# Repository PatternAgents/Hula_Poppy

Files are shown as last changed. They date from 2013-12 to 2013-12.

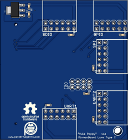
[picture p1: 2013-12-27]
Hula_Poppy/images/Hula_Poppy_thumb.png

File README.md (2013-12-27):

Hula Poppy
=============

PatternAgents Hula Poppy - Pmod Lure for Intel MinnowBoard

[PatternAgents Hula Poppy  
*PatternAgents Hula Poppy*](http://www.patternagents.com/projects/Hula_Poppy.html)

PatternAgents Hula Poppy - Pmod Lure for Intel MinnowBoard is a small adaptor board that allows
the Intel MinnowBoard to support Pmod Modules.

This work is licensed under a Creative Commons Attribution-ShareAlike 4.0 International License
[  
*Licensing CC BY-SA 4.0*](http://creativecommons.org/licenses/by-sa/4.0/)

It may be used for Educational, Personal, or Commercial Use, provided you keep these notices,
attribution, and share-alike. When you apply these licenses to material you create, 
it meets the Freedom Defined definition of a "Free Cultural Work". 
Free cultural works are the ones that can be most readily used, shared, 
and remixed by others, and go furthest toward creating a commons of freely reusable materials.

-------------------------------------------------------------------------------------------

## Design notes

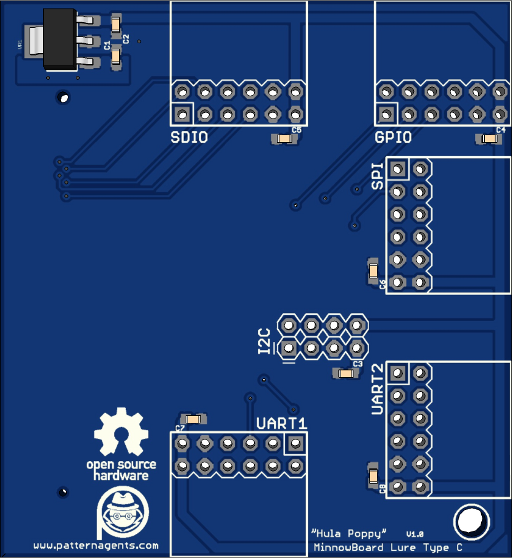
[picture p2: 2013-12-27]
Hula_Poppy/images/Hula_Poppy_top.png

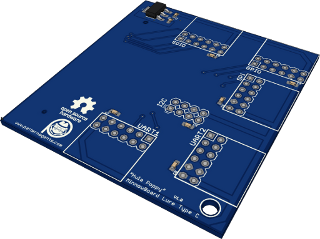
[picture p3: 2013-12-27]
Hula_Poppy/images/Hula_Poppy_model.png

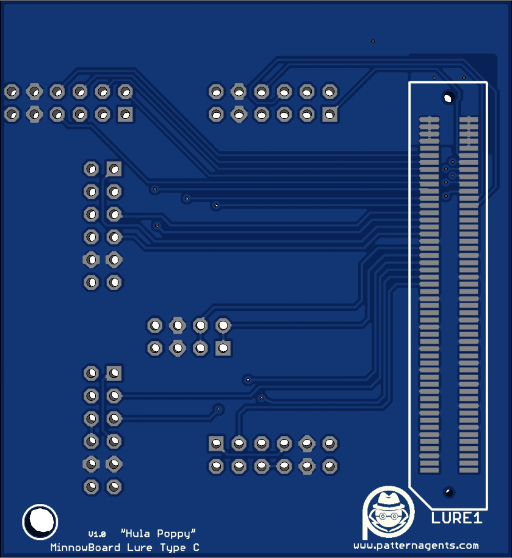
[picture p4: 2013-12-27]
Hula_Poppy/images/Hula_Poppy_bot.png

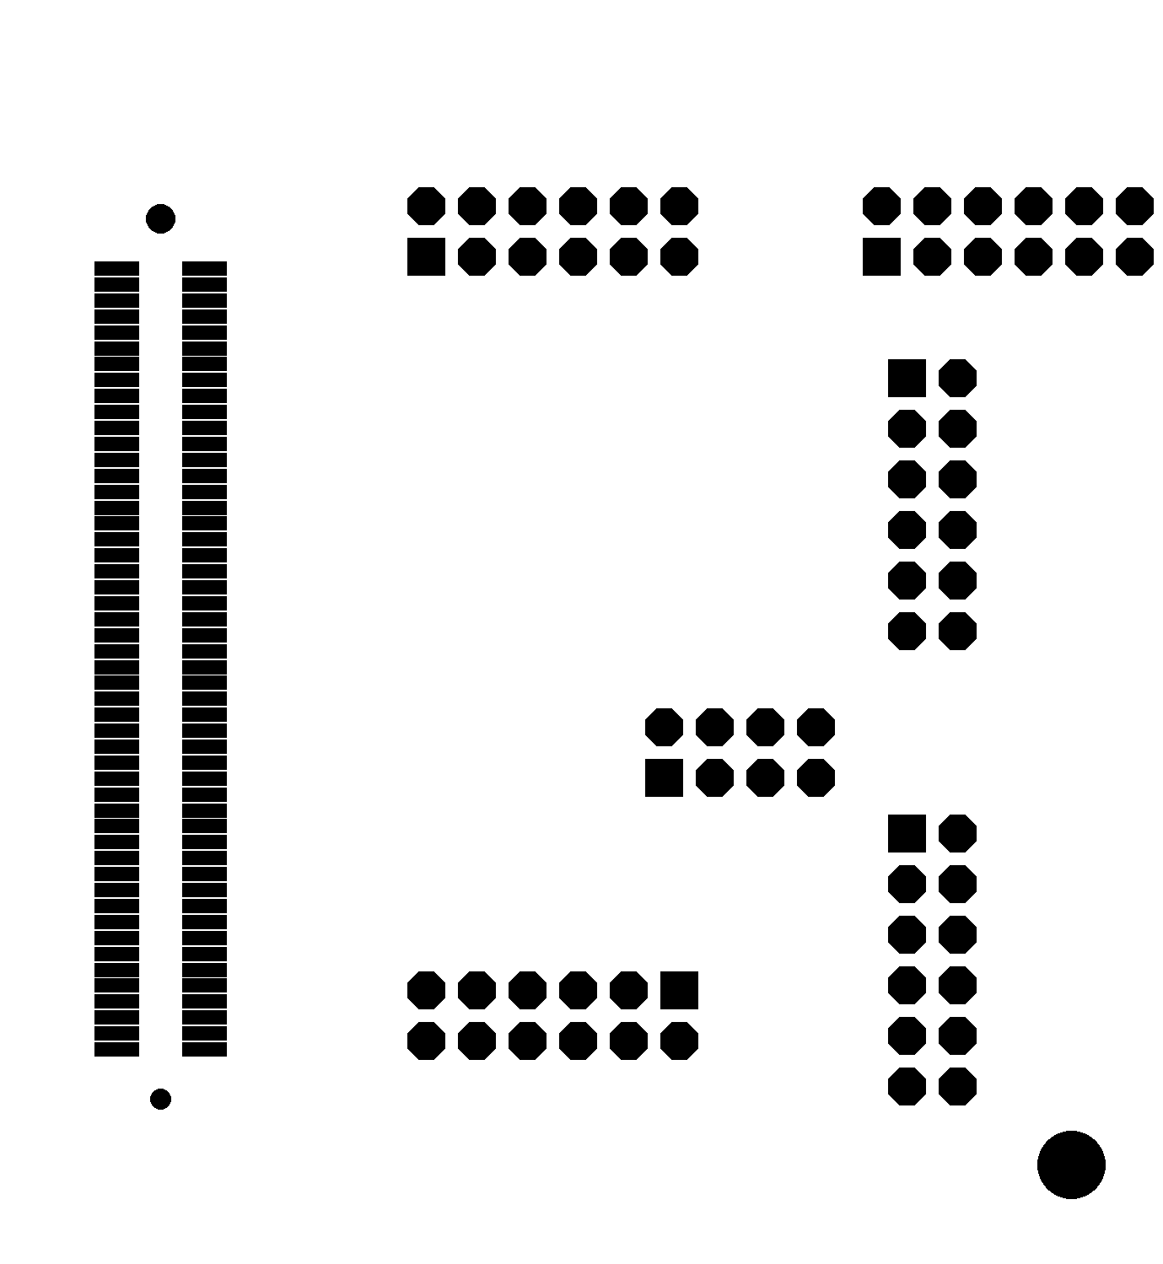
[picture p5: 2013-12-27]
Hula_Poppy/eagleUp/eagleUp_hula_poppy_bottom_mask.png

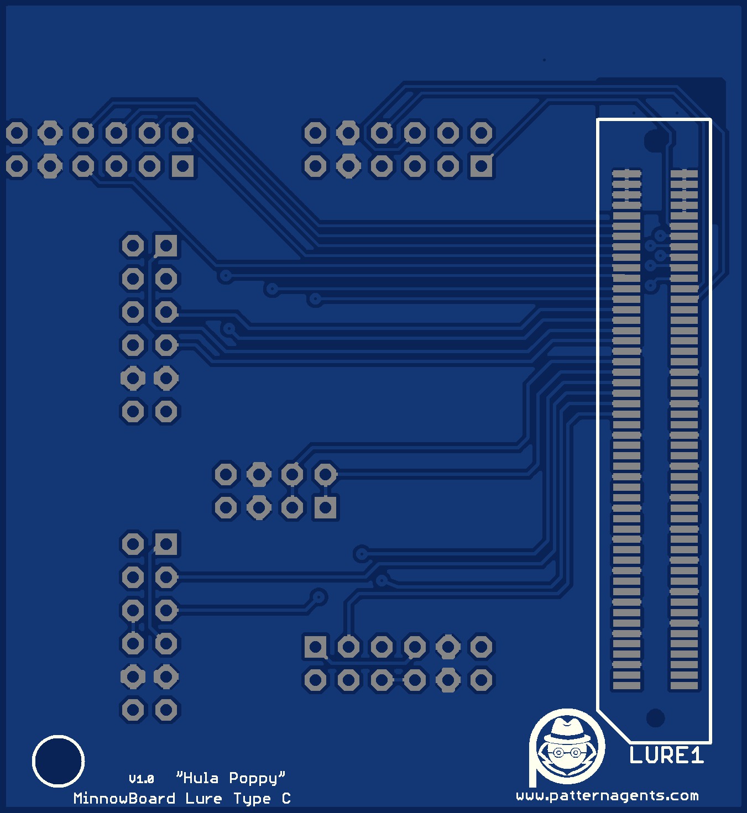
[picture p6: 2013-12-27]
Hula_Poppy/eagleUp/eagleUp_hula_poppy_board_bottom.jpg

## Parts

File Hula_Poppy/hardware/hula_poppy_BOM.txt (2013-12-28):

Partlist exported from hula_poppy.sch at 12/26/2013 7:46:43 PM

Part  Value                     Device                    Package               Description                                                                    
C1    10uF/6.3V                 CAP0603-CAP               0603-CAP              Capacitor                                                                      
C2    10uF/6.3V                 CAP0603-CAP               0603-CAP              Capacitor                                                                      
C3    0.1uF/6.3V                CAP0603-CAP               0603-CAP              Capacitor                                                                      
C4    0.1uF/6.3V                CAP0603-CAP               0603-CAP              Capacitor                                                                      
C5    0.1uF/6.3V                CAP0603-CAP               0603-CAP              Capacitor                                                                      
C6    0.1uF/6.3V                CAP0603-CAP               0603-CAP              Capacitor                                                                      
C7    0.1uF/6.3V                CAP0603-CAP               0603-CAP              Capacitor                                                                      
C8    0.1uF/6.3V                CAP0603-CAP               0603-CAP              Capacitor                                                                      
GPIO  PA_PMOD_GPIO_DIL_HOST     PA_PMOD_GPIO_DIL_HOST     PA_PMOD_DIL_FEMALE    PatternAgents Peripheral Module GPIO (Type 1A) Pattern                         
I2C   PA_PMOD_I2C_DIL_CABLE     PA_PMOD_I2C_DIL_CABLE     PA_PMOD_I2C_CABLE     PatternAgents Peripheral Module I2C (Standard) Pattern                         
LURE1 PA_MINNOW_LURE_BRD_TYPE_C PA_MINNOW_LURE_BRD_TYPE_C PA_LURE_TYPE_C        PatternAgents Minnow Lure Pattern                                              
SDIO  PA_PMOD_SDIO_DIL_HOST     PA_PMOD_SDIO_DIL_HOST     PA_PMOD_DIL_FEMALE    PatternAgents Peripheral Module SDIO (Type 2B) Pattern                         
SPI   PA_PMOD_SPI_DIL_HOST      PA_PMOD_SPI_DIL_HOST      PA_PMOD_DIL_FEMALE    PatternAgents Peripheral Module SPI (Type 2A) Pattern                          
U$6   PA_LOGO_SYMMED            PA_LOGO_SYMMED            PA_LOGO_AGENT_MED_SYM PatternAgents Logo Symbol                                                      
U$8   OSHW_LOGO_SYMWTXT         OSHW_LOGO_SYMWTXT         OSHW_LOGO_TEXT_SYM    OSHW_LOGO_SYM                                                                  
U$10  PA_LOGO_SYMMED            PA_LOGO_SYMMED            PA_LOGO_AGENT_MED_SYM PatternAgents Logo Symbol                                                      
UART1 PA_PMOD_UART_DIL_HOST     PA_PMOD_UART_DIL_HOST     PA_PMOD_DIL_FEMALE    PatternAgents Peripheral Module UART (Type 4A) Pattern                         
UART2 PA_PMOD_UART_DIL_HOST     PA_PMOD_UART_DIL_HOST     PA_PMOD_DIL_FEMALE    PatternAgents Peripheral Module UART (Type 4A) Pattern                         
VR1   V_REG_MIC2920             V_REG_MIC2920             SOT223                MIC2920A (http://www.micrel.com/_PDF/mic2920.pdf) - 400mA output LDO Regulator

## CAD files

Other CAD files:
Hula_Poppy/eagleUp/hula_poppy.skp

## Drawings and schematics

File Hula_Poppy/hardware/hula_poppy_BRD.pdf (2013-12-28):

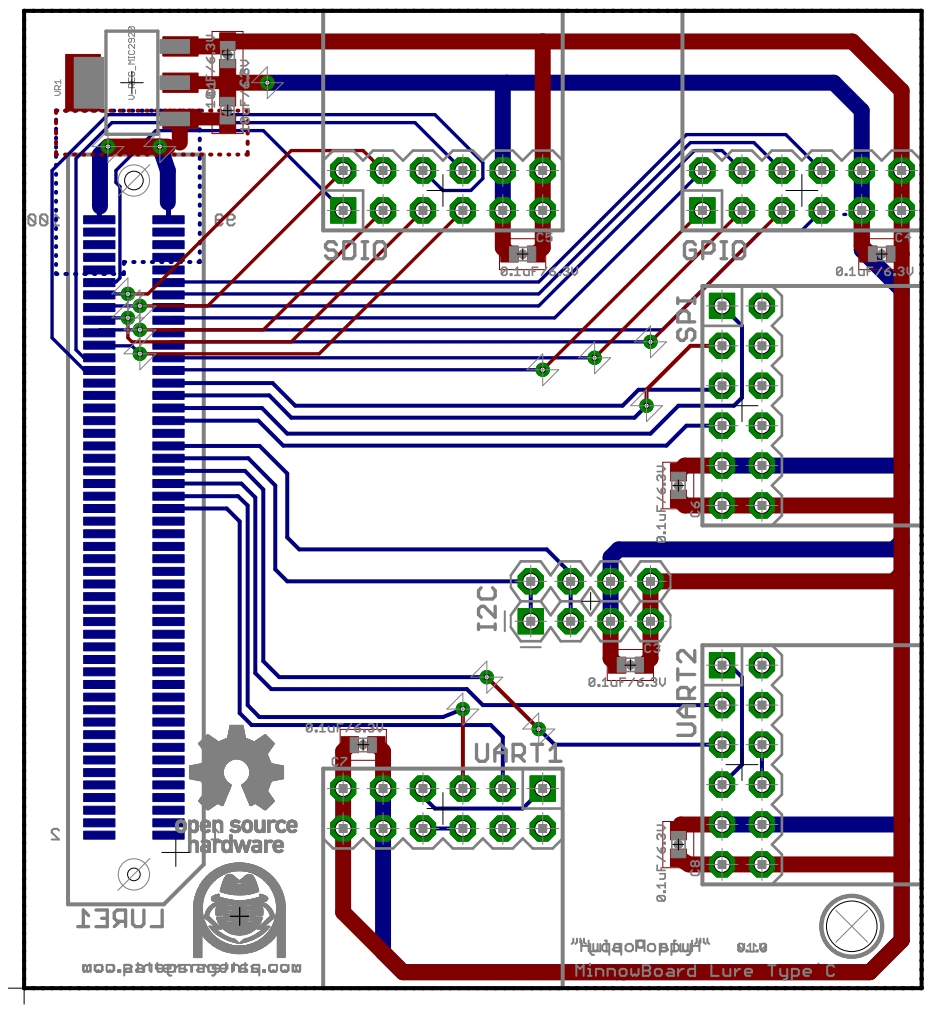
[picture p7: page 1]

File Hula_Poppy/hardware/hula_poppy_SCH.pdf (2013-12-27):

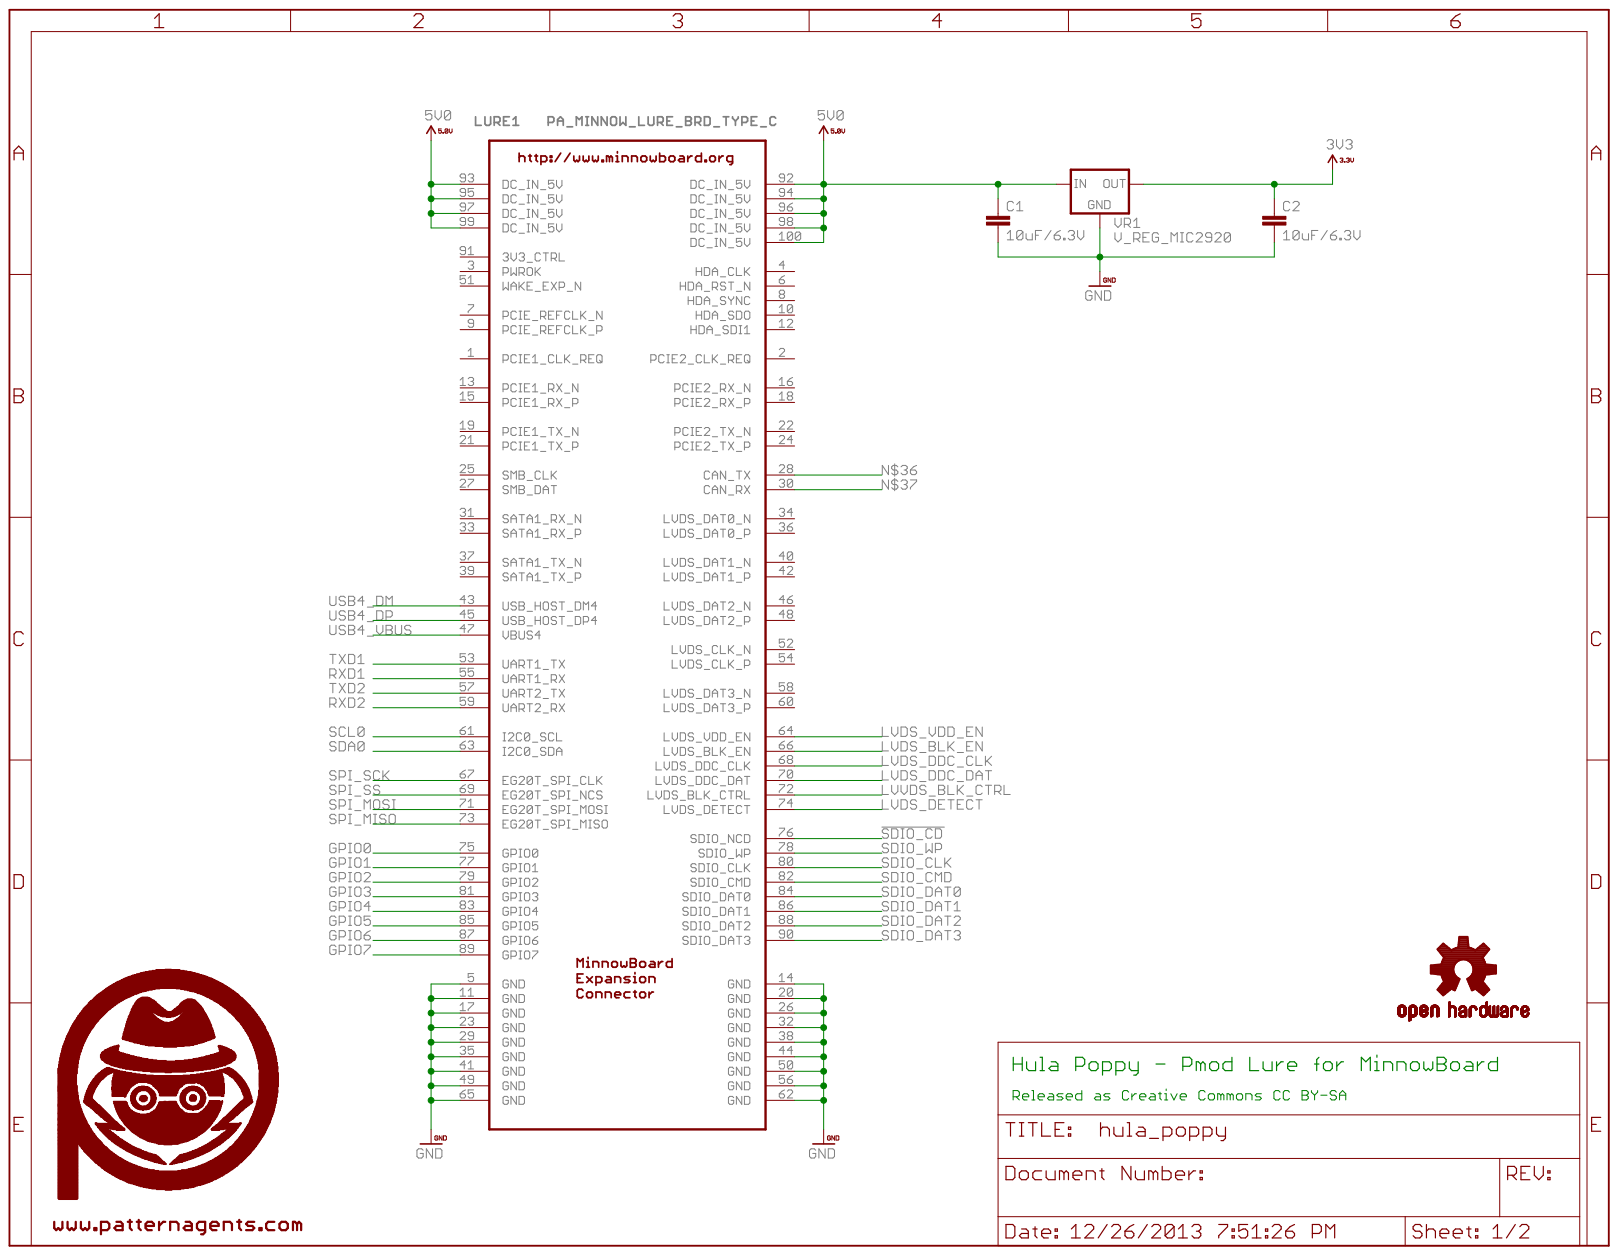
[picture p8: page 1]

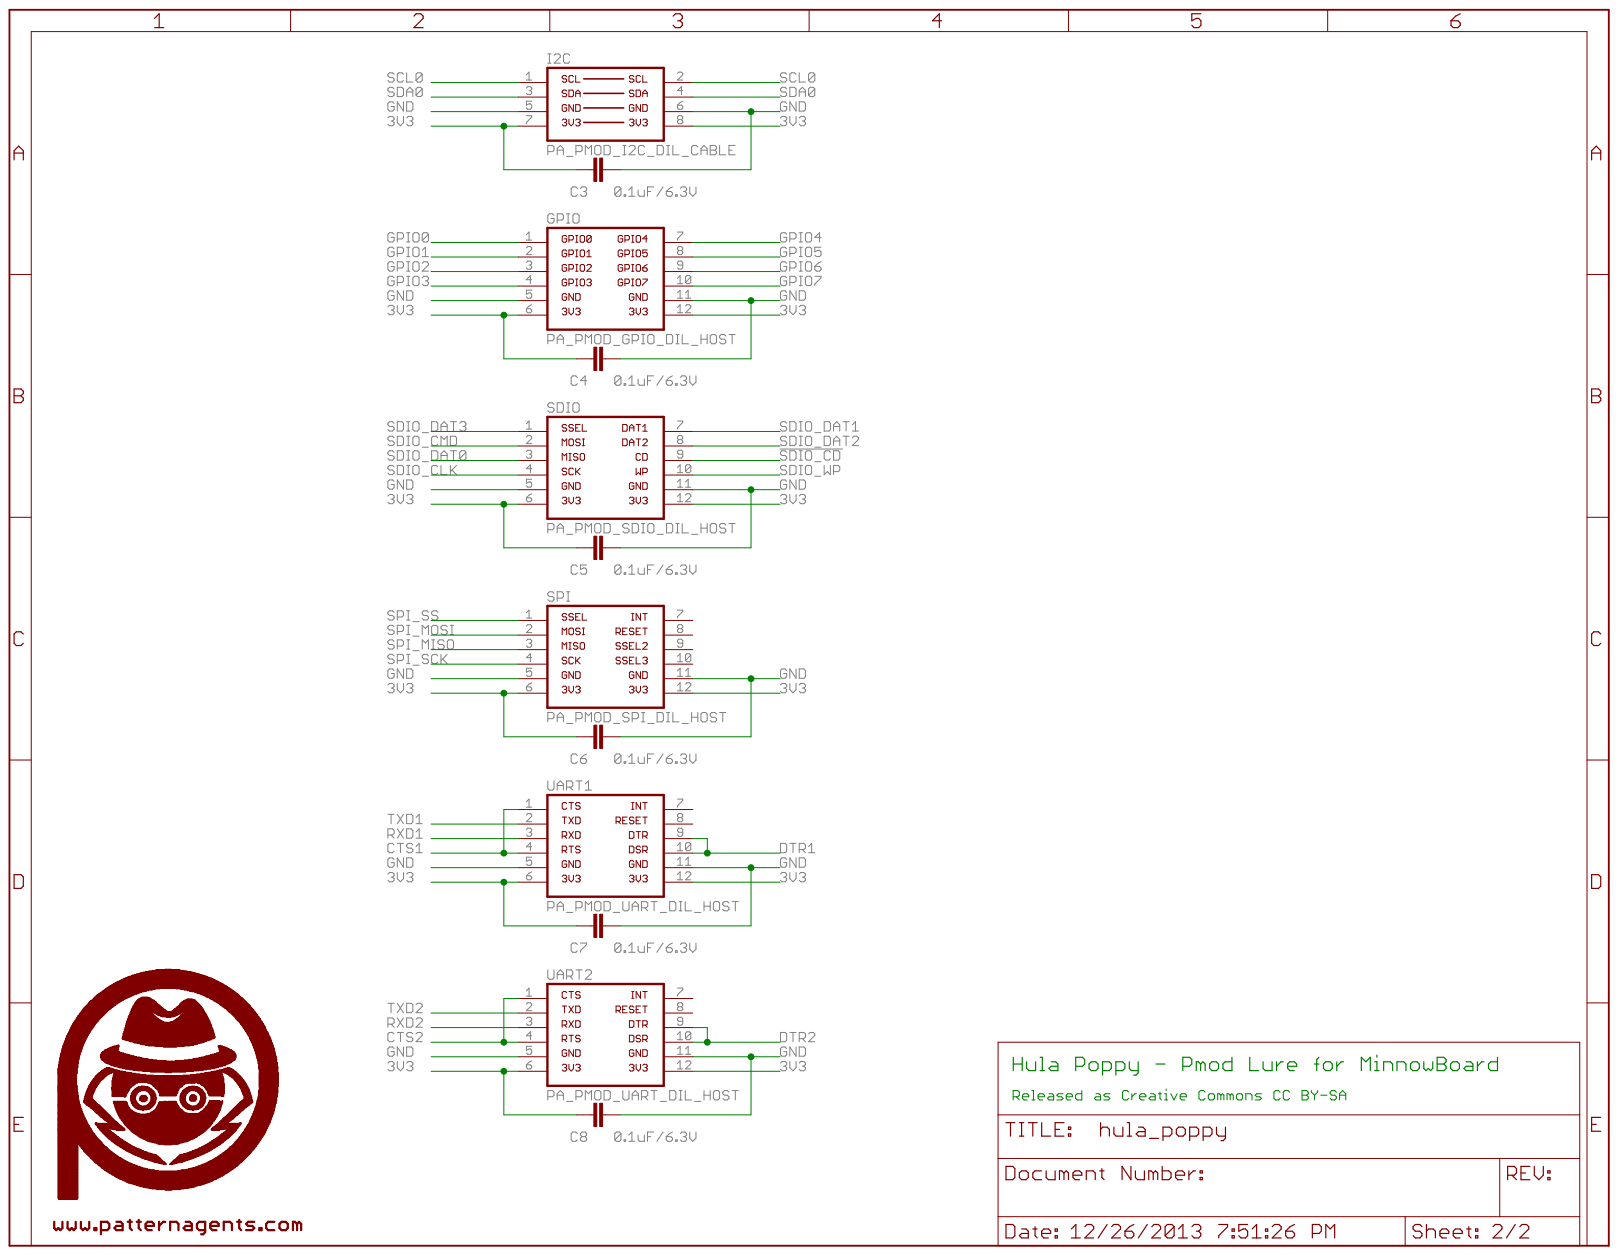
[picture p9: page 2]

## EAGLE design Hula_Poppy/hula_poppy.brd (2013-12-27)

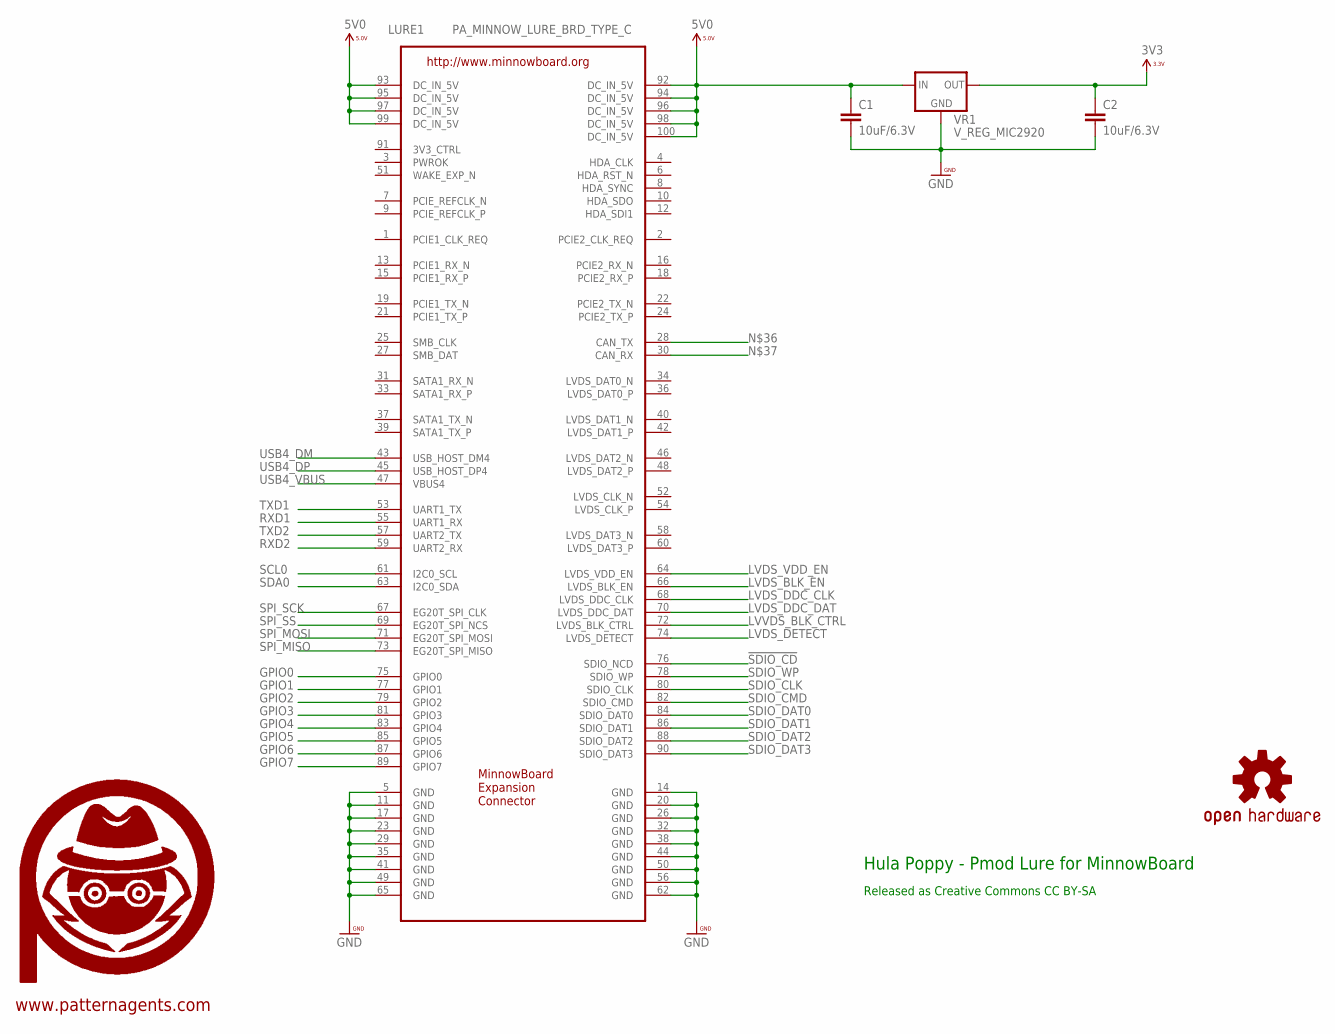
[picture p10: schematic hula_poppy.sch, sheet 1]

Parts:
C1, C2: 10uF/6.3V; 0603-CAP
LURE1: PA_MINNOW_LURE_BRD_TYPE_C; PA_LURE_TYPE_C
U$6: PA_LOGO_SYMMED; PA_LOGO_AGENT_MED_SYM
U$8: OSHW_LOGO_SYMWTXT; OSHW_LOGO_TEXT_SYM
VR1: V_REG_MIC2920; SOT223

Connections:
3V3: C2.1, VR1.3 (OUT); also elsewhere on the board
3V3_CTRL: LURE1.91 (3V3_CTRL)
5V0: C1.1, LURE1.92 (DC_IN_5V), LURE1.93 (DC_IN_5V), LURE1.94 (DC_IN_5V), LURE1.95 (DC_IN_5V), LURE1.96 (DC_IN_5V), LURE1.97 (DC_IN_5V), LURE1.98 (DC_IN_5V), LURE1.99 (DC_IN_5V), LURE1.100 (DC_IN_5V), VR1.1 (IN)
!SDIO_CD: LURE1.76 (SDIO_NCD); also elsewhere on the board
GND: C1.2, C2.2, LURE1.5 (GND), LURE1.11 (GND), LURE1.14 (GND), LURE1.17 (GND), LURE1.20 (GND), LURE1.23 (GND), LURE1.26 (GND), LURE1.29 (GND), LURE1.32 (GND), LURE1.35 (GND), LURE1.38 (GND), LURE1.41 (GND), LURE1.44 (GND), LURE1.49 (GND), LURE1.50 (GND), LURE1.56 (GND), LURE1.62 (GND), LURE1.65 (GND), VR1.2 (GND); also elsewhere on the board
GPIO0: LURE1.75 (GPIO0); also elsewhere on the board
GPIO1: LURE1.77 (GPIO1); also elsewhere on the board
GPIO2: LURE1.79 (GPIO2); also elsewhere on the board
GPIO3: LURE1.81 (GPIO3); also elsewhere on the board
GPIO4: LURE1.83 (GPIO4); also elsewhere on the board
GPIO5: LURE1.85 (GPIO5); also elsewhere on the board
GPIO6: LURE1.87 (GPIO6); also elsewhere on the board
GPIO7: LURE1.89 (GPIO7); also elsewhere on the board
LVDS_BLK_EN: LURE1.66 (LVDS_BLK_EN)
LVDS_DDC_CLK: LURE1.68 (LVDS_DDC_CLK)
LVDS_DDC_DAT: LURE1.70 (LVDS_DDC_DAT)
LVDS_DETECT: LURE1.74 (LVDS_DETECT)
LVDS_VDD_EN: LURE1.64 (LVDS_VDD_EN)
LVVDS_BLK_CTRL: LURE1.72 (LVDS_BLK_CTRL)
RXD1: LURE1.55 (UART1_RX); also elsewhere on the board
RXD2: LURE1.59 (UART2_RX); also elsewhere on the board
SCL0: LURE1.61 (I2C0_SCL); also elsewhere on the board
SDA0: LURE1.63 (I2C0_SDA); also elsewhere on the board
SDIO_CLK: LURE1.80 (SDIO_CLK); also elsewhere on the board
SDIO_CMD: LURE1.82 (SDIO_CMD); also elsewhere on the board
SDIO_DAT0: LURE1.84 (SDIO_DAT0); also elsewhere on the board
SDIO_DAT1: LURE1.86 (SDIO_DAT1); also elsewhere on the board
SDIO_DAT2: LURE1.88 (SDIO_DAT2); also elsewhere on the board
SDIO_DAT3: LURE1.90 (SDIO_DAT3); also elsewhere on the board
SDIO_WP: LURE1.78 (SDIO_WP); also elsewhere on the board
SPI_MISO: LURE1.73 (EG20T_SPI_MISO); also elsewhere on the board
SPI_MOSI: LURE1.71 (EG20T_SPI_MOSI); also elsewhere on the board
SPI_SCK: LURE1.67 (EG20T_SPI_CLK); also elsewhere on the board
SPI_SS: LURE1.69 (EG20T_SPI_NCS); also elsewhere on the board
TXD1: LURE1.53 (UART1_TX); also elsewhere on the board
TXD2: LURE1.57 (UART2_TX); also elsewhere on the board
USB4_DM: LURE1.43 (USB_HOST_DM4)
USB4_DP: LURE1.45 (USB_HOST_DP4)
USB4_VBUS: LURE1.47 (VBUS4)

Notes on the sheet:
Hula Poppy - Pmod Lure for MinnowBoard
Released as Creative Commons CC BY-SA
www.patternagents.com

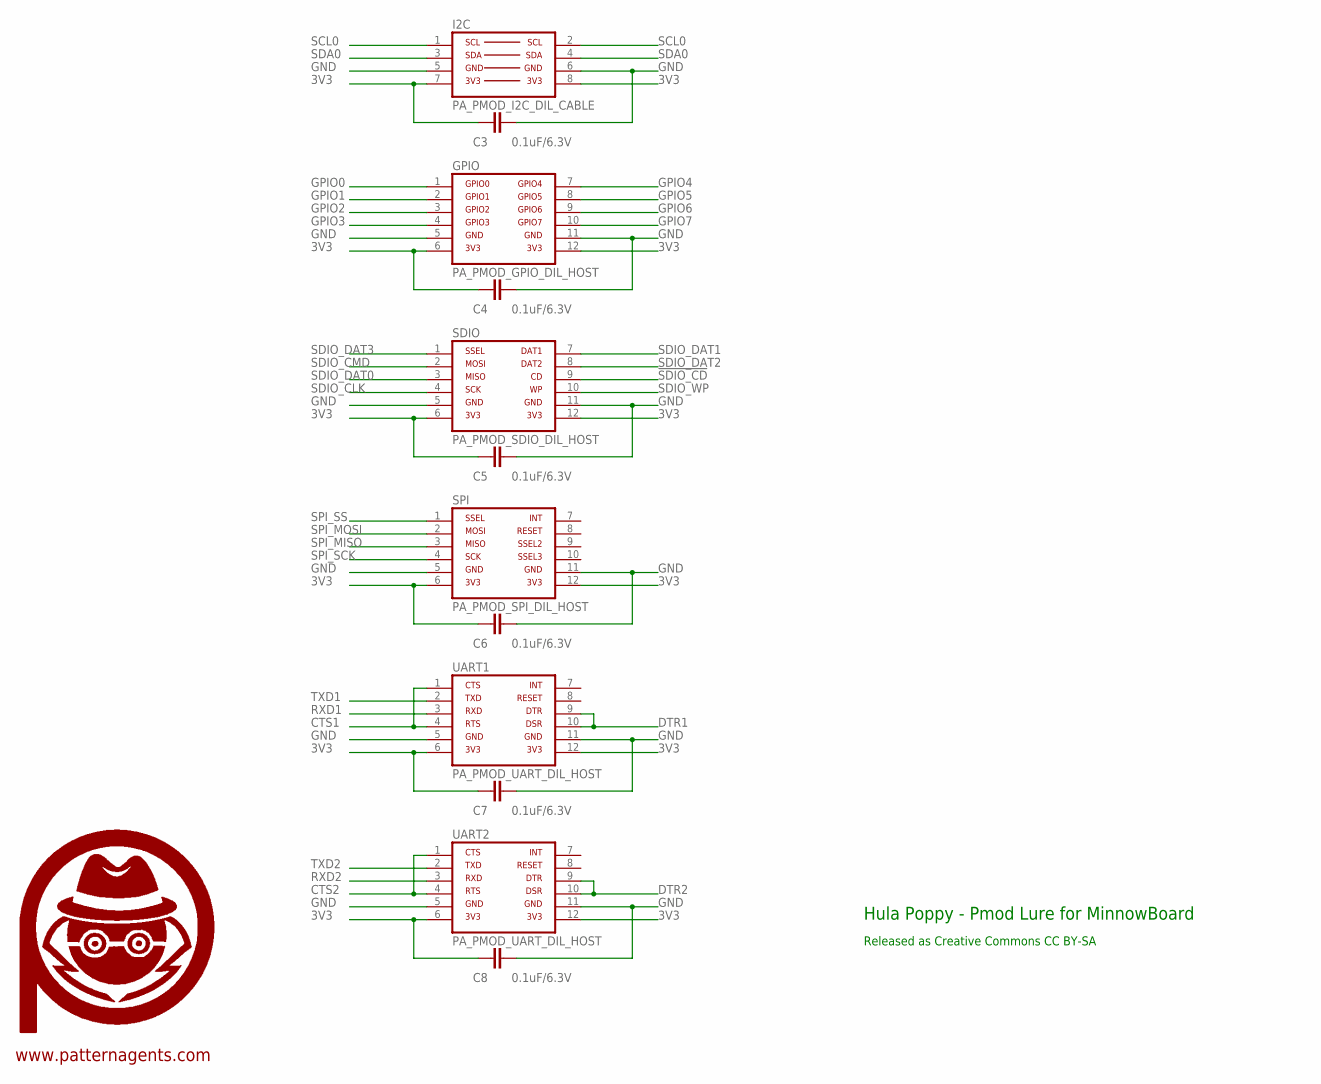
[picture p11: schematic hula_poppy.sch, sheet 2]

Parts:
C3, C4, C5, C6, C7, C8: 0.1uF/6.3V; 0603-CAP
GPIO: PA_PMOD_GPIO_DIL_HOST; PA_PMOD_DIL_FEMALE
I2C: PA_PMOD_I2C_DIL_CABLE; PA_PMOD_I2C_CABLE
SDIO: PA_PMOD_SDIO_DIL_HOST; PA_PMOD_DIL_FEMALE
SPI: PA_PMOD_SPI_DIL_HOST; PA_PMOD_DIL_FEMALE
U$10: PA_LOGO_SYMMED; PA_LOGO_AGENT_MED_SYM
UART1, UART2: PA_PMOD_UART_DIL_HOST; PA_PMOD_DIL_FEMALE

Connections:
3V3: C3.2, C4.2, C5.2, C6.2, C7.2, C8.2, GPIO.6, GPIO.12, I2C.7, I2C.8, SDIO.6, SDIO.12, SPI.6, SPI.12, UART1.6, UART1.12, UART2.6, UART2.12; also elsewhere on the board
!SDIO_CD: SDIO.9; also elsewhere on the board
CTS1: UART1.1, UART1.4
CTS2: UART2.1, UART2.4
DTR1: UART1.9, UART1.10
DTR2: UART2.9, UART2.10
GND: C3.1, C4.1, C5.1, C6.1, C7.1, C8.1, GPIO.5, GPIO.11, I2C.5, I2C.6, SDIO.5, SDIO.11, SPI.5, SPI.11, UART1.5, UART1.11, UART2.5, UART2.11; also elsewhere on the board
GPIO0: GPIO.1; also elsewhere on the board
GPIO1: GPIO.2; also elsewhere on the board
GPIO2: GPIO.3; also elsewhere on the board
GPIO3: GPIO.4; also elsewhere on the board
GPIO4: GPIO.7; also elsewhere on the board
GPIO5: GPIO.8; also elsewhere on the board
GPIO6: GPIO.9; also elsewhere on the board
GPIO7: GPIO.10; also elsewhere on the board
RXD1: UART1.3; also elsewhere on the board
RXD2: UART2.3; also elsewhere on the board
SCL0: I2C.1, I2C.2; also elsewhere on the board
SDA0: I2C.3, I2C.4; also elsewhere on the board
SDIO_CLK: SDIO.4; also elsewhere on the board
SDIO_CMD: SDIO.2; also elsewhere on the board
SDIO_DAT0: SDIO.3; also elsewhere on the board
SDIO_DAT1: SDIO.7; also elsewhere on the board
SDIO_DAT2: SDIO.8; also elsewhere on the board
SDIO_DAT3: SDIO.1; also elsewhere on the board
SDIO_WP: SDIO.10; also elsewhere on the board
SPI_MISO: SPI.3; also elsewhere on the board
SPI_MOSI: SPI.2; also elsewhere on the board
SPI_SCK: SPI.4; also elsewhere on the board
SPI_SS: SPI.1; also elsewhere on the board
TXD1: UART1.2; also elsewhere on the board
TXD2: UART2.2; also elsewhere on the board

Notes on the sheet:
Hula Poppy - Pmod Lure for MinnowBoard
Released as Creative Commons CC BY-SA
www.patternagents.com

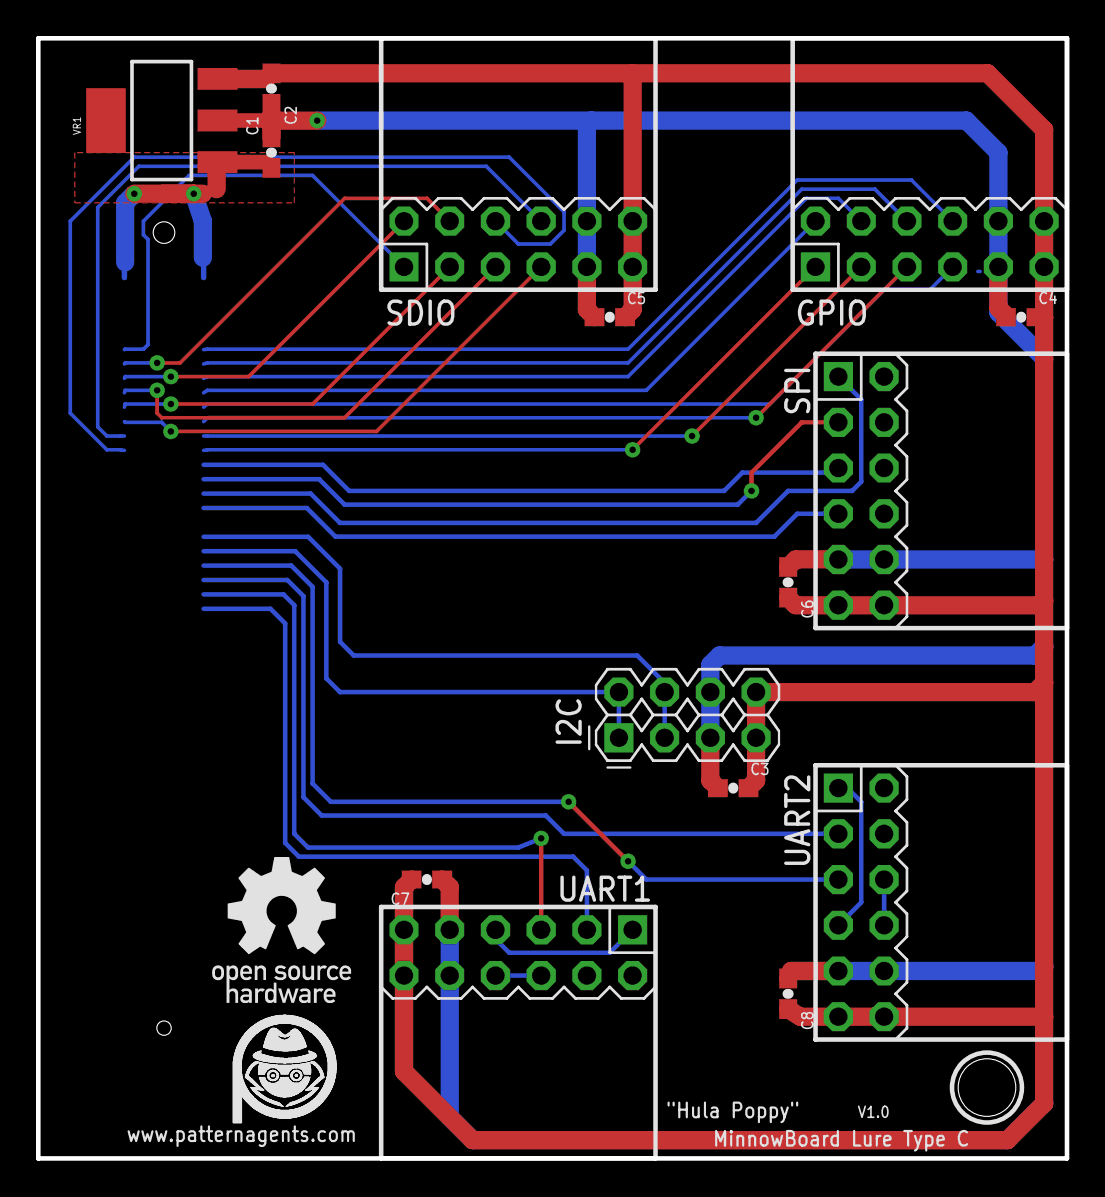
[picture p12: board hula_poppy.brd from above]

Board: 2 copper layers, 57.1 x 62.2 mm, 20 parts (1 on the bottom side), 33 nets.

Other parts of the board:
U$7: PA_LOGO_SYMMED; PA_LOGO_AGENT_MED_SYM

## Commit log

2013-12-27 Version 1.0 Initial Check-In
    Checking-In , Sir?
    [hula_poppy.brd, hula_poppy.sch, hula_poppy.skp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]
2013-12-28 Add more labels to board silkscreen, update gerbers

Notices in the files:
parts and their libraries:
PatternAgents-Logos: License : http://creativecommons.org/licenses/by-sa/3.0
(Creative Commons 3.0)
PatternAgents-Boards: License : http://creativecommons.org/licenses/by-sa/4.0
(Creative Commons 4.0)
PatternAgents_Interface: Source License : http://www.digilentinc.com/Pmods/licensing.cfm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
